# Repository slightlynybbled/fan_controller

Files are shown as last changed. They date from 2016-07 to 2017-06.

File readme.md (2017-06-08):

# Purpose #

This repository is for the hardware and firmware for a PC fan controller.  The
controller is intended to allow the user to multi-plex a single motherboard
output so that it may control up to 4 additional fans.  The project will feature:

 * Up to 4 outputs
 * Motherboard-controlled outputs for each with user speed scaling
 * Soft-start to reduce load on the motherboard
 * Speed control for each fan when a motherboard speed signal is not present
 
Details of the project may be found at [for(embed)](http://www.forembed.com/category/fan-controller.html).
 
# Project Status #

Firmware for v1.2 (optional thermistor control) is under development.

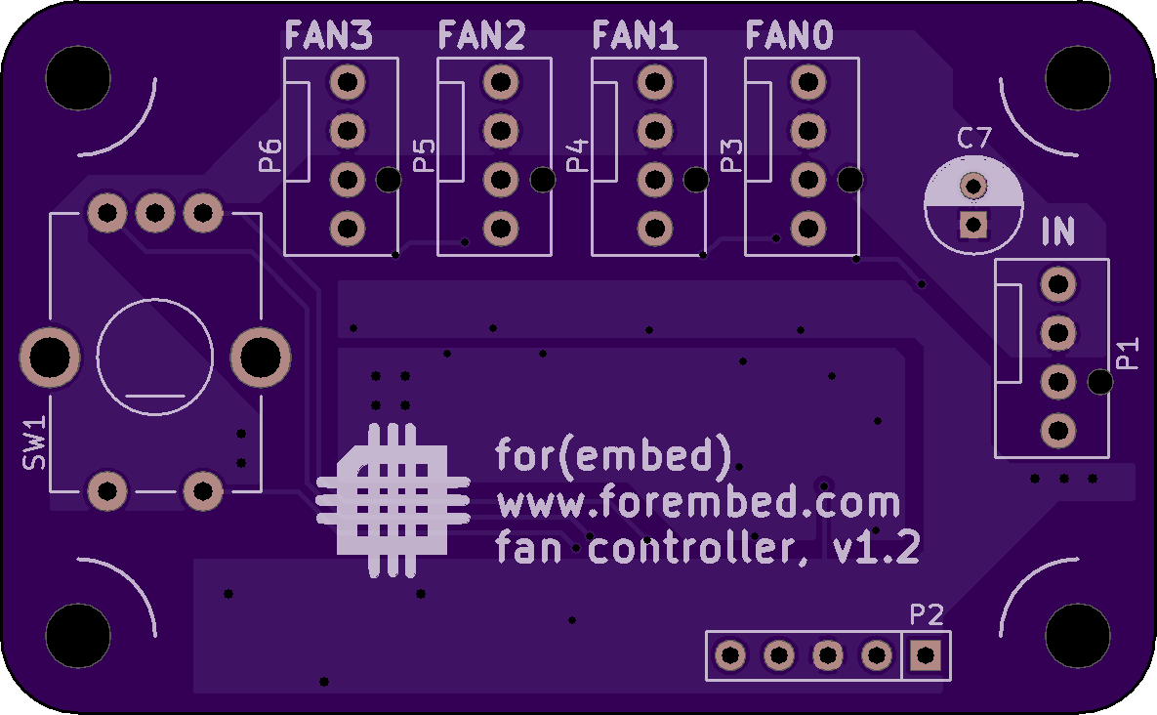
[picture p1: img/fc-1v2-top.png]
Top, v1.2

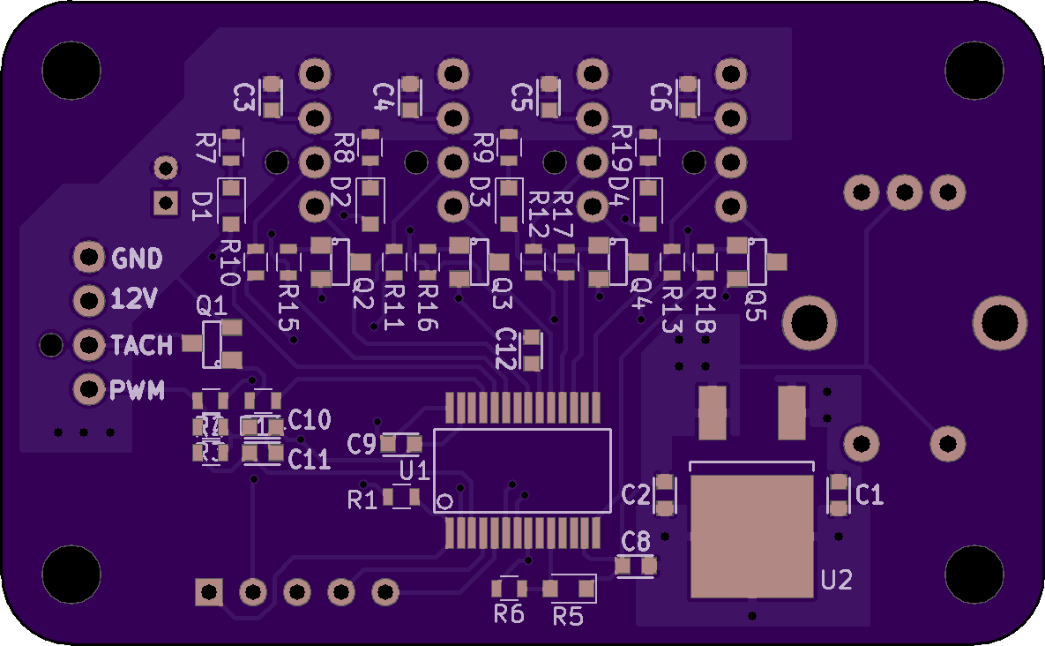
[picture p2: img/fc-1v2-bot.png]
Bottom, v1.2


Firmware for v1.1 is complete!  Testing has been completely successful!

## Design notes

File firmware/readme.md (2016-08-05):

# Purpose #

These source files are used to program the fan controller.

# Compiling #

To compile the software, you will need to have MPLAB X and MPLAB XC16 compiler installed on your system.
Within MPLAB X:

 1. Create a standalone project.
 2. Select the device - PIC24FV16KM202
 3. Select your debugger/programmer
 4. Add all *.c and *.s files to the project "Source Files"
 5. Add all *.h files to the project "Header Files"
 6. Compile

In xc16-gcc settings, be sure to include the directory with the header files or you will have trouble building:

 1. File -> Project Properties
 2. Click "xc16-gcc" on the left pane
 3. In the right pane, click the drop-down at the top and select "Preprocessing and messages"
 4. Under "C include dirs", be sure that the location for your header files is specified if it is outside
 of the project

# How to Flash #

To program the fan controller, you will need the hardware necessary to program a Microchip board.
I prefer to use an [ICD3](http://www.microchip.com/Developmenttools/ProductDetails.aspx?PartNO=DV164035),
but a [PICkit 3](http://www.microchip.com/Developmenttools/ProductDetails.aspx?PartNO=PG164130) should
work just as well.

The programming header on the board is compatible with the PICkit3 connector with no modification.  A
0.1" harness with the following pinout would have to be made for an ICD3:

 1. ~MCLR/Vpp
 2. Vdd
 3. Vss
 4. PGD
 5. PGC
 
Connect to the target and hit "Make and Program Device Main Project" button (looks like a green down arrow).

# Where to Next? #

Visit [for(embed)](http://www.forembed.com) for more projects and details!

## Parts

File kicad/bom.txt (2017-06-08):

Item	Qty	Reference	Manufacturer	MPN	Description	Datasheet
1	10	 C1, C2, C3, C4, C5, C6, C8, C9, C10, C11	Yageo	CC0603ZRY5V7BB104	capacitor, 100nF, 0603	
2	1	 C12	Yageo	CC0603ZRY5V7BB105	capacitor, ceramic, 1uF 16V	
3	1	 C7	Kemet	ESK476M035AC3AA	capacitor, alum, 47uF 35V, radial	
4	4	 D1, D2, D3, D4	OSRAM Opto Semiconductors Inc.	LG R971-KN-1	LED, green	
5	5	 P1, P3, P4, P5, P6	Molex	47053-1000	PC fan connector, 4-pin	
6	1	 P2				
7	5	 Q1, Q2, Q3, Q4, Q5	ON Semiconductor	MMBT3904LT1G	transistor, npn, 40V 0.2A SOT-23	
8	7	 R1, R3, R4, R10, R11, R12, R13	Yageo	RC0603JR-0710KL	resistor, 10k, 0603	
9	11	 R2, R6, R7, R8, R9, R14, R15, R16, R17, R18, R19	Yageo	RC0603JR-071KL	resistor, 1k, 0603	
10	1	 R5	Murata Electronics North America	NCP18XQ102J03RB	Thermistor, NTC	
11	1	 SW1	TT Electronics/BI	EN12-HS22AF30	encoder, rotary, top-adjust with switch	
12	1	 U1	Microchip, Inc.	PIC24FV16KM202-I/SS	microcontroller, 5V, 16MIPS	
13	1	 U2	ON Semiconductor	MC7805CDTG	voltage regulator, linear, 5V 1A, DPAK

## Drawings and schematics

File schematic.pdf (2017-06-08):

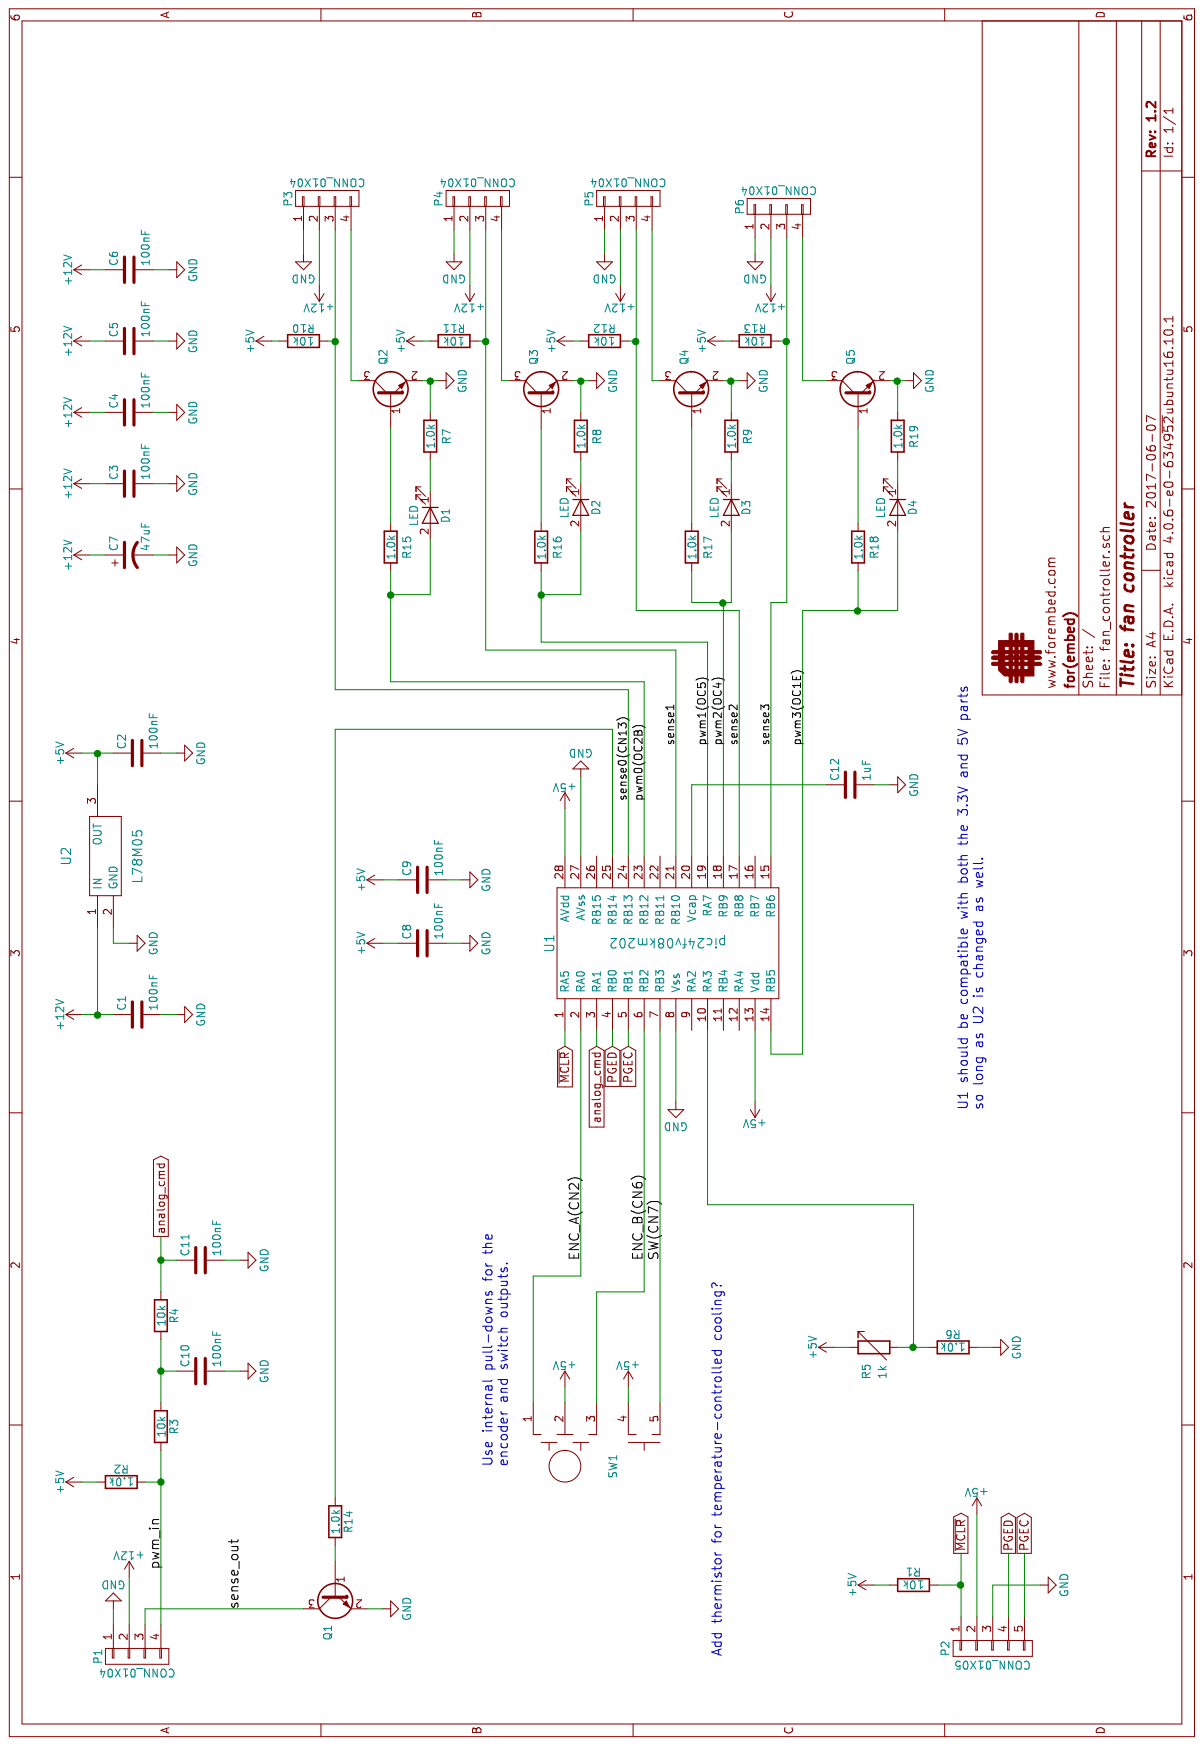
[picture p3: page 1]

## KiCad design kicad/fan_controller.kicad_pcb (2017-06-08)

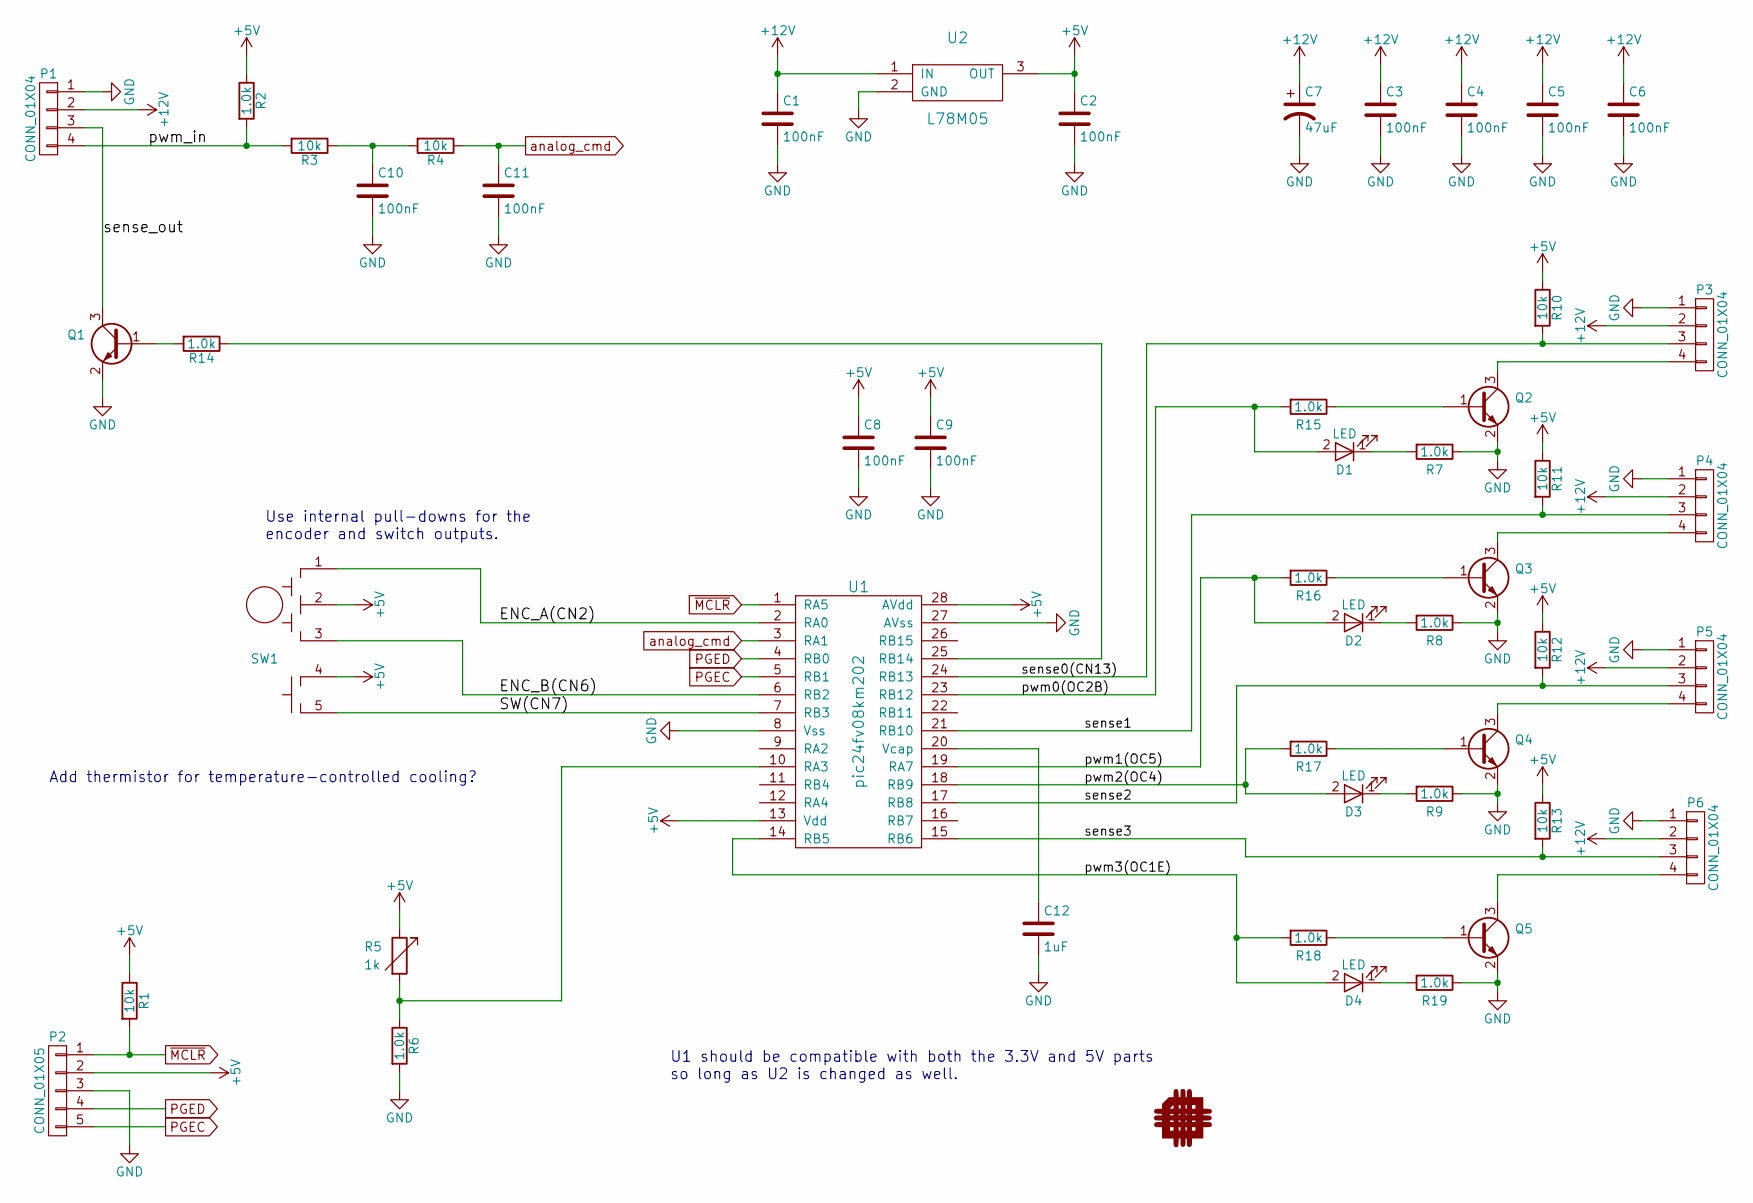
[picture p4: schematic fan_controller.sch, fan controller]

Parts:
C1, C2, C3, C4, C5, C6, C8, C9, C10, C11: 100nF; SM_0603; MPN CC0603ZRY5V7BB104
C7: 47uF; C_Radial_D5_L11_P2; MPN ESK476M035AC3AA
C12: 1uF; SM_0603; MPN CC0603ZRY5V7BB105
D1, D2, D3, D4: LED; D_0805; MPN LG R971-KN-1
P1, P3, P4, P5, P6: CONN_01X04; CONN_1x4_PC_FAN; MPN 47053-1000
P2: CONN_01X05; CON_1x5_0.1in
Q1, Q2, Q3, Q4, Q5: Q_NPN_BEC; SOT-23; MPN MMBT3904LT1G
R1, R3, R4, R10, R11, R12, R13: 10k; R_0603; MPN RC0603JR-0710KL
R2, R6, R7, R8, R9, R14, R15, R16, R17, R18, R19: 1.0k; R_0603; MPN RC0603JR-071KL
R5: 1k; D_0805; MPN NCP18XQ102J03RB
SW1: encoder_rotary_with_switch; encoder_EN12-HS; MPN EN12-HS22AF30
U1: pic24fv08km202; SSOP-28; MPN PIC24FV16KM202-I/SS
U2: L78M05; DPAK_TO-252; MPN MC7805CDTG

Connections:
+5V: C2.1, C8.1, C9.1, P2.2, R1.1, R2.1, R5.1, R10.1, R11.1, R12.1, R13.1, SW1.2, SW1.4, U1.13 (Vdd), U1.28 (AVdd), U2.3 (OUT)
+12V: C1.1, C3.1, C4.1, C5.1, C6.1, C7.1, P1.2, P3.2, P4.2, P5.2, P6.2, U2.1 (IN)
/ENC_A(CN2): SW1.1, U1.2 (RA0)
/ENC_B(CN6): SW1.3, U1.6 (RB2)
/SW(CN7): SW1.5, U1.7 (RB3)
/pwm0(OC2B): D1.2 (A), R15.2, U1.23 (RB12)
/pwm1(OC5): D2.2 (A), R16.2, U1.19 (RA7)
/pwm2(OC4): D3.2 (A), R17.2, U1.18 (RB9)
/pwm3(OC1E): D4.2 (A), R18.2, U1.14 (RB5)
/pwm_in: P1.4, R2.2, R3.2
/sense0(CN13): P3.3, R10.2, U1.24 (RB13)
/sense1: P4.3, R11.2, U1.21 (RB10)
/sense2: P5.3, R12.2, U1.17 (RB8)
/sense3: P6.3, R13.2, U1.15 (RB6)
/sense_out: P1.3, Q1.3 (C)
GND: C1.2, C2.2, C3.2, C4.2, C5.2, C6.2, C7.2, C8.2, C9.2, C10.2, C11.2, C12.2, P1.1, P2.3, P3.1, P4.1, P5.1, P6.1, Q1.2 (E), Q2.2 (E), Q3.2 (E), Q4.2 (E), Q5.2 (E), R6.2, R7.1, R8.1, R9.1, R19.1, U1.8 (Vss), U1.27 (AVss), U2.2 (GND)
unnamed: C10.1, R3.1, R4.2
unnamed: C12.1, U1.20 (Vcap)
unnamed: D1.1 (K), R7.2
unnamed: D2.1 (K), R8.2
unnamed: D3.1 (K), R9.2
unnamed: D4.1 (K), R19.2
unnamed: P3.4, Q2.3 (C)
unnamed: P4.4, Q3.3 (C)
unnamed: P5.4, Q4.3 (C)
unnamed: P6.4, Q5.3 (C)
unnamed: Q1.1 (B), R14.2
unnamed: Q2.1 (B), R15.1
unnamed: Q3.1 (B), R16.1
unnamed: Q4.1 (B), R17.1
unnamed: Q5.1 (B), R18.1
unnamed: R5.2, R6.1, U1.10 (RA3)
unnamed: R14.1, U1.25 (RB14)
PGEC: P2.5, U1.5 (RB1)
PGED: P2.4, U1.4 (RB0)
analog_cmd: C11.1, R4.1, U1.3 (RA1)
~MCLR: P2.1, R1.2, U1.1 (RA5)

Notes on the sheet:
U1 should be compatible with both the 3.3V and 5V parts so long as U2 is changed as well.
Add thermistor for temperature-controlled cooling?
Use internal pull-downs for the encoder and switch outputs.

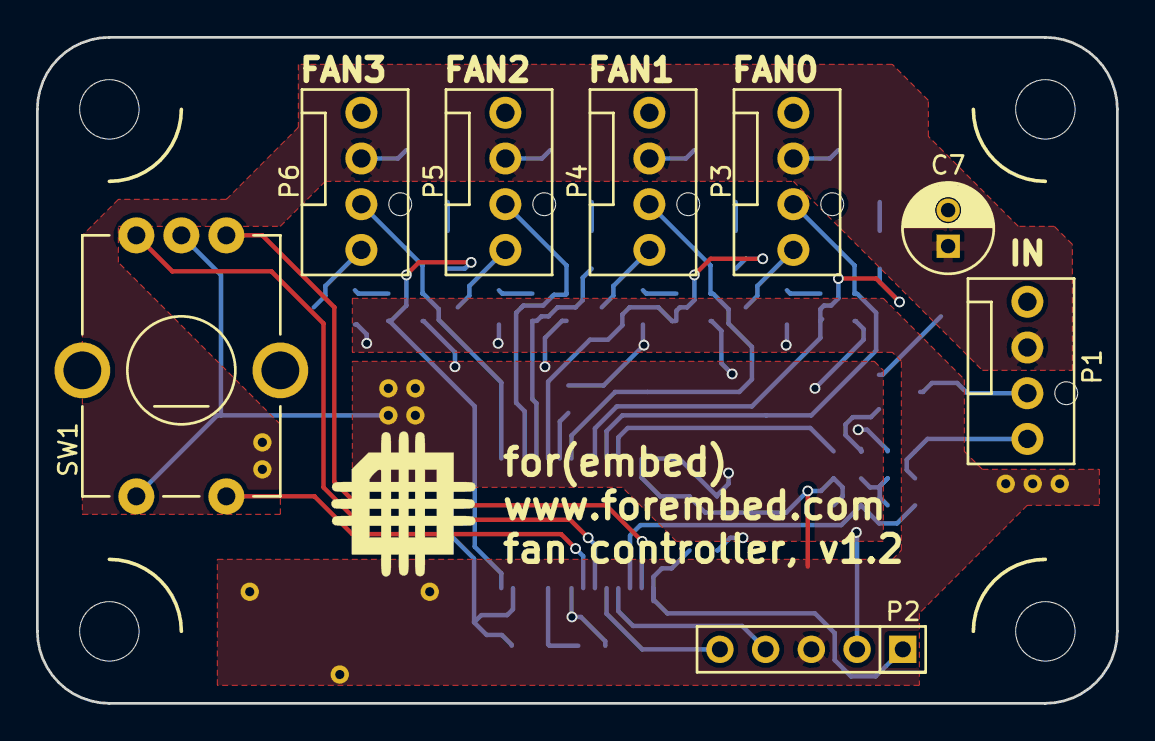
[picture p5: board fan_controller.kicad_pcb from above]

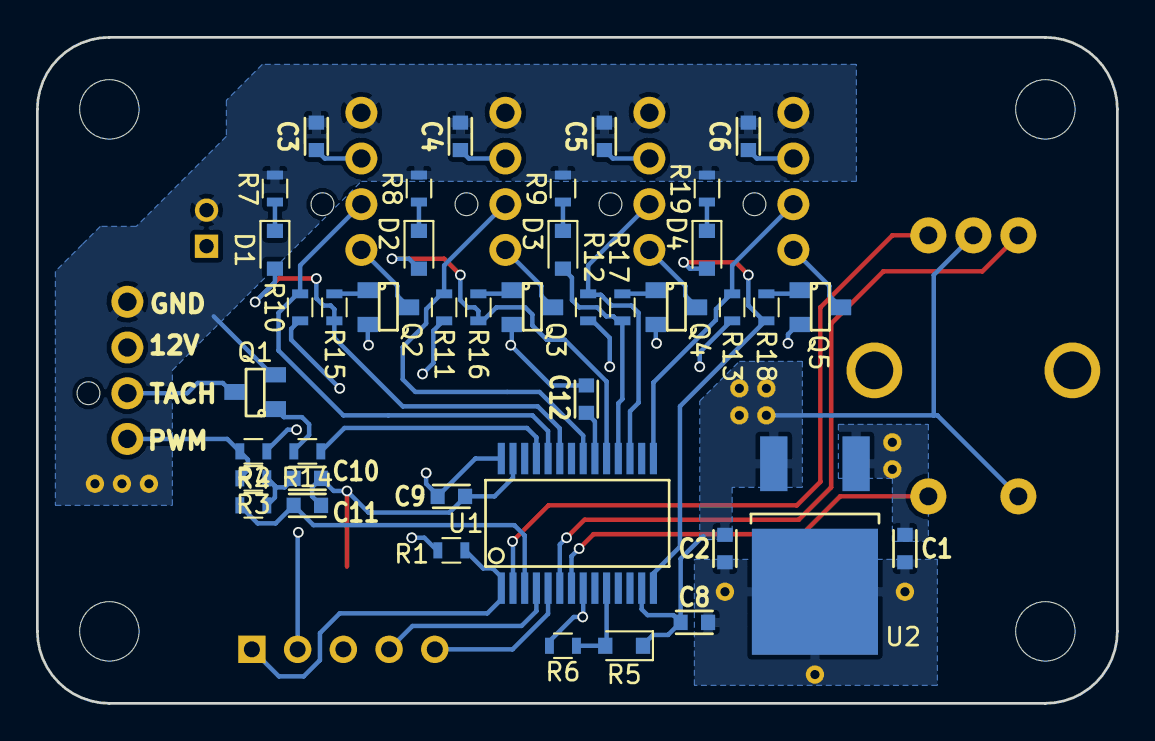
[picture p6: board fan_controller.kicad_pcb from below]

Board: 2 copper layers, 60.0 x 37.0 mm, 49 parts (41 on the bottom side), 37 nets.

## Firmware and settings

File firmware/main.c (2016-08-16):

/*
 * File:   main.c
 * Author: Jason
 */
#include "config.h"
#include "libmathq15.h"
#include "task.h"
#include "dio.h"
#include "eeprom.h"

/*********** Useful defines and macros ****************************************/
typedef enum {eINIT, eFAN_START, eNORMAL, eFAN_ADJ} FanState;

#define FAN_ADJUST_TIMEOUT  5000
#define MIN_INPUT_DC        2500
#define MIN_FAN_DC          3277
#define NUM_OF_FANS         4
#define MILLISECONDS_AFTER_PWM_TO_FULL_SPEED 100

#define SWITCH_PORT DIO_PORT_B
#define SWITCH_PIN  3
#define SWITCH      PORTBbits.RB3

#define ENC_A_PORT  DIO_PORT_A
#define ENC_A_PIN   0
#define ENC_B_PORT  DIO_PORT_B
#define ENC_B_PIN   2

/*********** Variable Declarations ********************************************/
FanState fanState = eINIT;
uint32_t lastEncoderTime = 0;
uint8_t switchPressed = 0;
q15_t encoderTurned = 0;

q15_t dcFan[NUM_OF_FANS] = {0};
q15_t targetDcFan[NUM_OF_FANS] = {0};

/*********** Function Declarations ********************************************/
void initOsc(void);
void initInterrupts(void);
void initIO(void);
void initPwm(void);
void initAdc(void);

void serviceFanState(void);
void serviceSwitch(void);
void serviceEncoder(void);

void setDutyCycleFan(uint8_t fan, q15_t dutyCycle);
void setDutyCycleFan0(q15_t dutyCycle);
void setDutyCycleFan1(q15_t dutyCycle);
void setDutyCycleFan2(q15_t dutyCycle);
void setDutyCycleFan3(q15_t dutyCycle);
q15_t rampDc(q15_t dc, q15_t targetDc);

/*********** Function Implementations *****************************************/
int main(void) {
    /* setup the hardware */
    initOsc();
    initInterrupts();
    initIO();
    initPwm();
    initAdc();
    
    /* initialize the task manager */
    TASK_init();
    
    /* add tasks */
    TASK_add(&serviceFanState, 10);
    TASK_add(&serviceSwitch, 1);
    TASK_add(&serviceEncoder, 1);
    
    TASK_manage();
    
    return 0;
}

/******************************************************************************/
/* Tasks below this line */
void serviceFanState(void){
    static uint8_t lastFanAdjusted = 0;
    
    /* ADC conversion to determine the input duty cycle */
    AD1CON1bits.SAMP = 0;
    while(!AD1CON1bits.DONE);   // ...wait for the ADC to finish...
    q15_t inputPwmDutyCycle = (q15_t)(ADC1BUF0 >> 1);
    
    switch(fanState){
        case eINIT:
        {
            uint8_t i;
            for(i = 0; i < NUM_OF_FANS; i++){
                dcFan[i] = 0;
                setDutyCycleFan(i, 0);
                
                targetDcFan[i] = EEPROM_read(i);
                
                if(targetDcFan[i] == 0){
                    targetDcFan[i] = 32767;
                    EEPROM_write(i, 32767);
                }
            }
            
            fanState = eFAN_START;
            switchPressed = 0;
            lastFanAdjusted = 0;
            
            break;
        }
        
        case eFAN_START:
        {
            /* start the fans */
            uint8_t i;
            for(i = 0; i < NUM_OF_FANS; i++){
                if(dcFan[i] != targetDcFan[i]){
                    dcFan[i] = rampDc(dcFan[i], targetDcFan[i]);
                    setDutyCycleFan(i, dcFan[i]);
                    break;
                }
            }
            
            /* determine when to exit the eFAN_START state */
            uint8_t exitCondition = 1;
            for(i = 0; i < NUM_OF_FANS; i++){
                if(dcFan[i] != targetDcFan[i])
                    exitCondition = 0;
            }
            if(exitCondition)
                fanState = eNORMAL;
            
            /* deal with the adjust button being pressed */
            if(switchPressed){
                fanState = eFAN_ADJ;
                lastFanAdjusted = 0;
                encoderTurned = 0;
            }
            switchPressed = 0;
            
            break;
        }
        
        case eNORMAL:
        {
            /* deal with the adjust button being pressed */
            if(switchPressed){
                fanState = eFAN_ADJ;
                lastFanAdjusted = 0;
                encoderTurned = 0;
            }
            switchPressed = 0;
            

            /* scale the target duty cycle to the input duty cycle */
            uint8_t i;
            for(i = 0; i < NUM_OF_FANS; i++){
                q15_t dc;
                
                dc = q15_mul(inputPwmDutyCycle, targetDcFan[i]);

                if(dc < MIN_FAN_DC)
                    dc = MIN_FAN_DC;
                
                if(inputPwmDutyCycle < MIN_INPUT_DC)
                    dc = 0;
                
                setDutyCycleFan(i, dc);
            }
            
            break;
        }
        
        case eFAN_ADJ:
        {
            /* when the encoder is being turned quickly, then move the
             * duty cycle quickly, else when the encoder is being turned
             * slowly, then move the duty cycle slowly */
            q15_t increment, dc;
            if((encoderTurned < 4) && (encoderTurned > -4))
                increment = 10 * encoderTurned;
            else
                increment = 100 * encoderTurned;
            
            /* dc = inc + lastDc */
            dc = q15_add(increment, dcFan[lastFanAdjusted]);
            
            /* place limits on the duty cycle */
            if(dc < 0)
                dc = 0;
            else if((dcFan[lastFanAdjusted] > 0) && (dc < MIN_FAN_DC))
                dc = 0;
            else if((dcFan[lastFanAdjusted] == 0) && (dc > 0))
                dc = MIN_FAN_DC;
            
            dcFan[lastFanAdjusted] = dc;
            
            encoderTurned = 0;
            
            /* deal with a timeout */
            if(TASK_getTime() > (lastEncoderTime + FAN_ADJUST_TIMEOUT)){
                fanState = eINIT;
                
                targetDcFan[lastFanAdjusted] = dcFan[lastFanAdjusted];
                EEPROM_write(lastFanAdjusted, dcFan[lastFanAdjusted]);
            }
            
            /* deal with the adjust button being pressed */
            if(switchPressed){
                targetDcFan[lastFanAdjusted] = dcFan[lastFanAdjusted];
                EEPROM_write(lastFanAdjusted, dcFan[lastFanAdjusted]);
                
                lastFanAdjusted++;
                if(lastFanAdjusted > NUM_OF_FANS)
                    lastFanAdjusted = 0;
            }
            switchPressed = 0;
            
            /* set the appropriate duty cycles - only the fan currently
             * being adjusted should be greater than 0 */
            uint8_t i;
            for(i = 0; i < NUM_OF_FANS; i++){
                if(i == lastFanAdjusted){
                    setDutyCycleFan(i, dcFan[i]);
                }else{
                    setDutyCycleFan(i, 0);
                }
            }
            
            break;
        }
        
        default:
        {
            while(1);   // programmer's trap
        }
        
    }
}

void serviceSwitch(void){
    static uint8_t switchArray = 0;
    static uint8_t state = 0;
    
    /* debounce */
    switchArray <<= 1;
    if(SWITCH){
        switchArray |= 0x01;
    }else{
        switchArray &= 0xfe;
    }
    
    /* edge detector */
    if((switchArray == 0xff) && (state == 0)){
        /* switch just released */
        state = 1;
        lastEncoderTime = TASK_getTime();
        
        switchPressed = 1;
    }else if((switchArray == 0x00) && (state == 1)){
        /* switch just pressed */
        state = 0;
        lastEncoderTime = TASK_getTime();
    }
}

void serviceEncoder(void){
    /* I found this routine at 
     * https://www.circuitsathome.com/mcu/reading-rotary-encoder-on-arduino 
     * appears to work well enough and I would like to give credit where
     * it is due. */
    
    static int8_t enc_states[] = {0,-1,1,0,1,0,0,-1,-1,0,0,1,0,1,-1,0};
    static uint8_t old_AB = 0;
    
    uint8_t new_AB = PORTAbits.RA0 | (PORTBbits.RB2 << 1);
    
    old_AB <<= 2;
    old_AB |= new_AB;
    
    int8_t state = enc_states[(old_AB & 0x0f)];
    
    if(state == 1){
        /* counter-clockwise */
        lastEncoderTime = TASK_getTime();
        encoderTurned--;    // reverse the direction of CW and CCW
    }else if(state == -1){
        /* clockwise */
        lastEncoderTime = TASK_getTime();
        encoderTurned++;    // reverse the direction of CW and CCW
    }
}

/******************************************************************************/
/* Helper functions below this line */
void setDutyCycleFan(uint8_t fan, q15_t dutyCycle){
    switch(fan){
        case 0:     setDutyCycleFan0(dutyCycle);    break;
        case 1:     setDutyCycleFan1(dutyCycle);    break;
        case 2:     setDutyCycleFan2(dutyCycle);    break;
        case 3:     setDutyCycleFan3(dutyCycle);    break;
        default:                                    break;
    }
}

void setDutyCycleFan0(q15_t dutyCycle){
    CCP2RB = q15_mul(dutyCycle, CCP2PRL);
    
    /* when CCPxRB == 0, PWM doesn't update properly */
    if(CCP2RB < 2)
        CCP2RB = 2;
    else if(CCP2RB >= CCP2PRL)
        CCP2RB = CCP2PRL - 1;
    
    return;
}

void setDutyCycleFan1(q15_t dutyCycle){
    CCP5RB = q15_mul(dutyCycle, CCP5PRL);
    
    /* when CCPxRB == 0, PWM doesn't update properly */
    if(CCP5RB < 2)
        CCP5RB = 2;
    else if(CCP5RB >= CCP5PRL)
        CCP5RB = CCP5PRL - 1;
}

void setDutyCycleFan2(q15_t dutyCycle){
    CCP4RB = q15_mul(dutyCycle, CCP4PRL);
    
    /* when CCPxRB == 0, PWM doesn't update properly */
    if(CCP4RB < 2)
        CCP4RB = 2;
    else if(CCP4RB >= CCP4PRL)
        CCP4RB = CCP4PRL - 1;
}

void setDutyCycleFan3(q15_t dutyCycle){
    CCP1RB = q15_mul(dutyCycle, CCP1PRL);
    
    /* when CCPxRB < 2, PWM doesn't update properly */
    if(CCP1RB < 2)
        CCP1RB = 2;
    else if(CCP1RB >= CCP1PRL)
        CCP1RB = CCP1PRL - 1;
    
    return;
}

q15_t rampDc(q15_t dc, q15_t targetDc){
    const q15_t rampIncrement = 50;
    q15_t newDc = 0;
    
    if(targetDc < MIN_FAN_DC){
        newDc = 0;
    }else if((targetDc >= MIN_FAN_DC) && (dc == 0)){
        newDc = MIN_FAN_DC;
    }else if(targetDc > dc){
        /* ramp the fan to its target */
        q15_t dcDiff = q15_add(targetDc, -dc);
        if(dcDiff > rampIncrement)
            dcDiff = rampIncrement;
        
        newDc = q15_add(dc, dcDiff);
    }
    
    return newDc;
}

/******************************************************************************/
/* Initialization functions below this line */
void initOsc(void){
    CLKDIV = 0;

    return;
}

void initInterrupts(void){
    /* configure the global interrupt conditions */
    /* interrupt nesting disabled, DISI instruction active */
    INTCON1 = 0x8000;
    INTCON2 = 0x4000;
    
    /* allow change notification interrupts */
    IFS1bits.CNIF = 0;
    IEC1bits.CNIE = 1;
    
    /* enable CN interrupt for PWM and tach measurements */
    CNEN1bits.CN14IE = 1;
    CNEN1bits.CN13IE = 1;
    
    return;
}

void initIO(void){
    /* debugging outputs */
    DIO_makeOutput(DIO_PORT_A, 2);
    DIO_makeOutput(DIO_PORT_A, 3);
        
    /* encoder inputs */
    DIO_makeInput(ENC_A_PORT, ENC_A_PIN);
    DIO_makeInput(ENC_B_PORT, ENC_B_PIN);
    DIO_makeInput(SWITCH_PORT, SWITCH_PIN);
    
    DIO_makeDigital(ENC_A_PORT, ENC_A_PIN);
    DIO_makeDigital(ENC_B_PORT, ENC_B_PIN);
    DIO_makeDigital(SWITCH_PORT, SWITCH_PIN);
    
    /* enable switch and encoder pull-down resistors */
    CNPD1bits.CN2PDE = 1;
    CNPD1bits.CN6PDE = 1;
    CNPD1bits.CN7PDE = 1;
    
    /* fan PWM outputs */
    DIO_makeOutput(DIO_PORT_B, 12); /* PWM fan0 */
    DIO_makeOutput(DIO_PORT_A, 7);  /* PWM fan1 */
    DIO_makeOutput(DIO_PORT_B, 9);  /* PWM fan2 */
    DIO_makeOutput(DIO_PORT_B, 5);  /* PWM fan3 */
    
    /* fan tach inputs */
    DIO_makeInput(DIO_PORT_B, 13);  /* tach fan0 */
    DIO_makeInput(DIO_PORT_B, 10);  /* tach fan1 */
    DIO_makeInput(DIO_PORT_B, 8);   /* tach fan2 */
    DIO_makeInput(DIO_PORT_B, 6);   /* tach fan3 */
    
    DIO_makeDigital(DIO_PORT_B, 13);
    DIO_makeDigital(DIO_PORT_B, 8);
    DIO_makeDigital(DIO_PORT_B, 6);
    
    /* PWM input, should be configured as an input */
    DIO_makeInput(DIO_PORT_A, 1);
    DIO_makeAnalog(DIO_PORT_A, 1);
    
    /* tach output */
    DIO_makeOutput(DIO_PORT_B, 14);
}

void initPwm(void){
    /* Initialize MCCP/SCCP modules */
    
    /* period registers */
    CCP1PRH = CCP2PRH = CCP4PRH = CCP5PRH = 0;
    CCP1PRL = CCP2PRL = CCP4PRL = CCP5PRL = 640;
    
    CCP1CON1L = CCP2CON1L = CCP4CON1L = CCP5CON1L = 0x0005;
    CCP1CON1H = CCP2CON1H = CCP4CON1H = CCP5CON1H = 0x0000;
    CCP1CON2L = CCP2CON2L = CCP4CON2L = CCP5CON2L = 0x0000;
    
    CCP2CON2H = 0x8200; // enable output 0C2B (fan0)
    CCP5CON2H = 0x8100; // enable output OC5 (fan1)
    CCP4CON2H = 0x8100; // enable output OC4 (fan2)
    CCP1CON2H = 0x9000; // enable output OC1E (fan3)
    
    CCP1CON3L = CCP2CON3L = 0;  // dead time disabled
    
    /**/
    CCP1CON3H = CCP2CON3H = CCP4CON3H = CCP5CON3H = 0;
    CCP1CON3Hbits.POLACE = CCP4CON3Hbits.POLACE = CCP5CON3Hbits.POLACE = 1;
    CCP2CON3Hbits.POLBDF = 1;
    
    CCP1CON1Lbits.CCPON = 
            CCP2CON1Lbits.CCPON = 
            CCP4CON1Lbits.CCPON = 
            CCP5CON1Lbits.CCPON = 1;
    
    /* duty cycle registers */
    CCP1RA = CCP2RA = CCP4RA = CCP5RA = 0;
    CCP1RB = CCP2RB = CCP4RB = CCP5RB = 0;
    
    /* set the initial duty cycles */
    setDutyCycleFan0(0);
    setDutyCycleFan1(0);
    setDutyCycleFan2(0);
    setDutyCycleFan3(0);
    
    return;
}

void initAdc(void){
    /* set up the analog pin as analog inputs */
    DIO_makeInput(DIO_PORT_A, 1);
    DIO_makeAnalog(DIO_PORT_A, 1);
    
    AD1CON1 = 0x0200;   /* Clear sample bit to trigger conversion
                         * FORM = left justified  */
    AD1CON2 = 0x0000;   /* Set AD1IF after every 1 samples */
    AD1CON3 = 0x0007;   /* Sample time = 1Tad, Tad = 8 * Tcy */
    
    AD1CHS = 0x0101;    /* AN1 */
    AD1CSSL = 0;
    
    AD1CON1bits.ADON = 1; // turn ADC ON
    AD1CON1bits.ASAM = 1; // auto-sample
    
    return;
}

void _ISR _CNInterrupt(void){
    IFS1bits.CNIF = 0;
    
    /* reflect FAN0 tach to the motherboard tach */
    static uint8_t lastTachFan0 = 0;
    uint8_t tachFan0 = PORTBbits.RB13;
    if(tachFan0 != lastTachFan0){
        /* set the output tach based on fan 0 */
        if(tachFan0 == 0){
            LATBbits.LATB14 = 0;
        }else{
            LATBbits.LATB14 = 1;
        }
    }
    lastTachFan0 = tachFan0;
    
    LATAbits.LATA2 = 0;
}

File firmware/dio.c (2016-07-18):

#include "dio.h"
#include <xc.h>

#define DIO_OUTPUT  0
#define DIO_INPUT   1
#define DIO_DIGITAL 0
#define DIO_ANALOG  1

void DIO_makeInput(Port port, uint8_t pin){
    uint16_t mask = 1 << pin;
    
    switch(port){
        case DIO_PORT_A:
        {
            TRISA |= mask;
            break;
        }
        
        case DIO_PORT_B:
        {
            TRISB |= mask;
            break;
        }
        
        default: while(1);
    }
}

void DIO_makeOutput(Port port, uint8_t pin){
    uint16_t mask = ~(1 << pin);
    
    switch(port){
        case DIO_PORT_A:
        {
            TRISA &= mask;
            break;
        }
        
        case DIO_PORT_B:
        {
            TRISB &= mask;
            break;
        }
        
        default: while(1);
    }
}

void DIO_makeAnalog(Port port, uint8_t pin){
    uint16_t mask = 1 << pin;
    
    switch(port){
        case DIO_PORT_A:
        {
            ANSA |= mask;
            break;
        }
        
        case DIO_PORT_B:
        {
            ANSB |= mask;
            break;
        }
        
        default: while(1);
    }
}

void DIO_makeDigital(Port port, uint8_t pin){
    uint16_t mask = ~(1 << pin);
    
    switch(port){
        case DIO_PORT_A:
        {
            ANSA &= mask;
            break;
        }
        
        case DIO_PORT_B:
        {
            ANSB &= mask;
            break;
        }
        
        default: while(1);
    }
}

uint8_t DIO_readPin(Port port, uint8_t pin){
    uint16_t mask = (1 << pin);
    
    uint16_t portValue = 0;
    uint8_t pinState = 0;
    
    switch(port){
        case DIO_PORT_A:
        {
            portValue = PORTA & mask;
            break;
        }
        
        case DIO_PORT_B:
        {
            portValue = PORTB & mask;
            break;
        }
        
        default: while(1);
    }
    
    if(portValue > 0)
        pinState = 1;
    
    return pinState;
}

void DIO_setPin(Port port, uint8_t pin){
    uint16_t mask = 1 << pin;
    
    switch(port){
        case DIO_PORT_A:
        {
            LATA |= mask;
            break;
        }
        
        case DIO_PORT_B:
        {
            LATB |= mask;
            break;
        }
        
        default: while(1);
    }
}

void DIO_clearPin(Port port, uint8_t pin){
    uint16_t mask = ~(1 << pin);
    
    switch(port){
        case DIO_PORT_A:
        {
            LATA &= mask;
            break;
        }
        
        case DIO_PORT_B:
        {
            LATB &= mask;
            break;
        }
        
        default: while(1);
    }
}

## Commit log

2016-07-11 Initial design
    [fan_controller.kicad_pcb, fan_controller.sch]
2016-07-11 Added PDF schematic for easy review
2016-07-18 Oscillator and task manager along with some PWMs working
    [main.c]
2016-07-18 All PWMs work
2016-07-18 Inverted the output PWMs
    [main.c]
2016-07-18 CN interrupts working
2016-07-18 Encoder being polled by the task manager
2016-07-18 Fixed bug in code
    [dio.c]
2016-07-18 Reading and debouncing the switch
2016-07-18 Added state machine to fan controller that has a timeout
2016-07-18 Removed debugging pin toggle
2016-07-20 Fixed an error in which the address wasn't even as the device requires
2016-07-20 Fixed the initializer check for the EEPROM
    [main.c]
2016-07-20 Fixed state machine and PWM on 'normal' state
    [main.c]
2016-07-21 Activated CN pull-down resistors within the uC
2016-07-21 Added hardware files for v1.1 schematic and board
    [fan_controller.kicad_pcb, fan_controller.sch]
2016-07-21 PDF print
2016-08-05 Added missing BOM information
    [fan_controller.sch]
2016-08-05 Updated pin functionality for v1.1 of the board
2016-08-16 Added ADC conversion to measure input PWM
2016-08-16 Added net label
    [fan_controller.kicad_pcb, fan_controller.sch]
2017-06-08 Added LEDs, fixed #2
    [fan_controller.kicad_pcb, fan_controller.sch]
2017-06-08 Added logo
    [fan_controller.kicad_pcb]
2017-06-08 Updating to v1.2 (adding thermistor and LED)
    [fan_controller.sch]
2017-06-08 Corrected silkscreen, added images to readme
    [fan_controller.kicad_pcb]
